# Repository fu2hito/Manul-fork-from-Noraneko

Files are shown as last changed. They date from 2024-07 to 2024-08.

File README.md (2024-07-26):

# Manul(Low profile GRIN layout keyboard based on Noraneko42GR)

## 概要

Manul（Noraneko42GR choc v2）は、[@darakuneko](https://github.com/darakuneko)さんの[Noranekoキーボード](https://github.com/darakuneko/Noraneko)の[Noraneko42gr v1.2](noraneko42gr/v1.2)を元にスイッチをChoc v2(Lofree Ghost switch)に変更したものです。

Manulは[Coffee License](LICENCE_JA.original)にしたがって作成しています。

このREADMEはNoraneko42GRとManul v1.0, 2.0で書きました。

## バージョン

### v1.0

<blockquote class="twitter-tweet"><p lang="ja" dir="ltr">Keyboard: Noraneko42GR / choc v2 mod<br>Switch: いろいろ / Lofree Ghost<br>Keycap: OSA Profile Black Transparent PC Keycap / Maya Imprint nSA<a href="https://twitter.com/hashtag/KEEB_PD?src=hash&amp;ref_src=twsrc%5Etfw">#KEEB_PD</a> <a href="https://twitter.com/hashtag/KEEB_PD_R200?src=hash&amp;ref_src=twsrc%5Etfw">#KEEB_PD_R200</a> <a href="https://t.co/kMvqZM04f1">pic.twitter.com/kMvqZM04f1</a></p>&mdash; fujihito (@fu2hito) <a href="https://twitter.com/fu2hito/status/1797206774899945583?ref_src=twsrc%5Etfw">June 2, 2024</a></blockquote> 

* PCB, Firmwareの動作確認済み
* PCBに設計ミスがあり、空中配線が必要
  * GP13(row0)が配線されていない
  * ソケットの干渉を避ける目的でパッドを削除する必要があり、キーマトリクスの変更とFirmwareの書き換えを含めた修正が必要
* Plateはネジ穴が不足、過度の切り抜きで剛性が不足

### v2.0

<blockquote class="twitter-tweet"><p lang="ja" dir="ltr">Keyboard: Manul(based on Noraneko42GR)<br>Switch: Haute42 Crystal<br>Keycap: Milky White Mist XSA Height<a href="https://twitter.com/hashtag/KEEB_PD?src=hash&amp;ref_src=twsrc%5Etfw">#KEEB_PD</a> <a href="https://twitter.com/hashtag/KEEB_PD_R207?src=hash&amp;ref_src=twsrc%5Etfw">#KEEB_PD_R207</a><br><br>基板、プレート修正して一応の完成です。名前は平べったい猫でマヌルに <a href="https://t.co/Jkr2DkHb3N">pic.twitter.com/Jkr2DkHb3N</a></p>&mdash; fujihito (@fu2hito) <a href="https://twitter.com/fu2hito/status/1814964786993754403?ref_src=twsrc%5Etfw">July 21, 2024</a></blockquote>

* PCBの設計変更
  * ピンアサインの変更を含めて、空中配線が不要になるように変更
  * キーマトリクスの変更
* Plateの設計変更
  * ネジ穴の追加
  * 切り抜きの変更

## Acknowledgement

Manulは直接的には以下の方々のおかげで作成されました。ありがとうございます。

### Noraneko42GR

Manulは[@darakuneko](https://github.com/darakuneko)さんの[Noraneko42gr v1.2](https://github.com/darakuneko/Noraneko/tree/main/noraneko42gr/v1.2)をベースに作成されました。

Noranekoキーボードシリーズは、[Coffee License](https://github.com/darakuneko/Noraneko/blob/main/LICENSE_JA)です。

KiCADファイルやFirmware、プレートファイルは、Noraneko42GRのものを使用しています。

### Choc v2スイッチのフットプリント

Choc v2スイッチのフットプリントは、[サリチル酸](https://github.com/Salicylic-acid3)さんの[KiCAD_FootPrint](https://github.com/Salicylic-acid3/KiCAD_FootPrint)を[フォークしたもの](https://github.com/fu2hito/KiCAD_FootPrint)を使用しました。1.5u等のフットプリントを追加しています。

KiCAD_FootPrintは、[MIT License](https://github.com/Salicylic-acid3/KiCAD_FootPrint/blob/master/Licence.txt)です。

その他[サリチル酸](https://x.com/Salicylic_acid3)さんにはdiscordや書籍などでお世話になっております。

### GPK FWBuilder

Firmwareのビルドは再び[@darakuneko](https://github.com/darakuneko)さんの[GPK FWBuilder](https://github.com/darakuneko/gpk_fwbuilder)を使用しています。
これなしでは私の自キ活は成り立ちません。

Intel Macだと10.1以降動かなくなっているので、Macの更新に迫られています。

### シリアルLEDについて

[monksoffunkJP](https://x.com/monksoffunkJP)さんの[記事](https://25keys.com/2022/05/28/rp2040_sk6812mini/)の下記引用部分を参考に配線しました。きれいに光っております。アドバイスなどあればIssueにてお願いします。

```
もうひとつ解決法があります。しかも面倒なパーツは一切要らない方法です。
それは、WS2812B V5とSK6812mini(-e)を併用するというものです。WS2812Bは3.3VのDINを受けてもDOUTは5Vレベルですので、先にWS2812Bをアンダーグロウとして使い、そのあとにSK6812mini-eをバックライトとして使えば仕様上は動作すると思います。あるいはWS2812Bをレベル変換のために1個だけ載せるという手もあるかもしれませんね。どちらも試したことはないので動かなかったらごめんなさい。
```

### スイッチ裏のRP2040 Zeroの配置について

スイッチのLEDまどを下向きにしたため、RP2040 Zeroのフットプリントはスイッチに干渉します。そのため、使用しないピンのパッドを削除しました。

この配線しないピンのパッドを削除するアイデアは、参考URLを失念しております。申し訳ございません。
たしかTwitterかdiscordで見たものだったかと思います。ありがとうございます。

## ライセンス

* MIT License
  * [LICENSE](./LICENSE)

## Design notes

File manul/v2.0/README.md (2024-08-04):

# Manul

Manul v2 image

ManulはNoraneko42GRをベースにした42キーのGRINレイアウトキーボードです。Lofree Ghostスイッチの利用を前提としたChoc v2ソケット対応です。

## パーツ

* PCB --- 1枚
* アクリルプレート トップ --- 1枚
  * PCBより上
  * 2 mm
* アクリルプレート ボトム1 --- 2枚
  * PCBより下
  * 2 mm
* アクリルプレート ボトム2 --- 1枚
  * PCBより下
  * 2 mm
* M2スペーサー 3mmまたは3.5mm --- 7個
* M2ネジ 3mm --- 14個
* RP2040-Zero --- 1個
* コンスルー --- 18ピン（MAC8 XB-3 高さ3mm以上）
  * ピンヘッダ
  * 干渉を避けるためカットします
* 1N4148W --- 42個
* WS2812B --- 6個
* SK6812MINI-E --- 42個
* Choc V2スイッチ --- 42個
  * アクリルプレート ボトム1が干渉するため、一部のピンの多いChoc V2スイッチは利用できません
* MXキーキャップ（ロープロファイルがおすすめ） --- 42個
* ゴム足 --- 任意の数

## ファームウェア

手順はNoraneko42GRと[同様](./README.original.md)です。Manulには抵抗はありません。

* [ファームウェア](./firmware/manul/)
  * WIP: ビルド済みファイルはアップロードしていません。
* [Vialサポート](https://get.vial.today/)

## はんだ付け

はんだ付けはNoraneko42GRと[同様](./README.original.md)です。Manulには抵抗がありません。

RP2040-Zero、ダイオード、LED、ソケットをはんだ付けします。
いずれもはんだ付けの向きに注意してください。

## 組み立て

1. アクリルプレート トップと一緒にスイッチをPCBに取り付けます。
2. M2スペーサーを取り付けます。まずトップ側にネジ止めします。
3. アクリルプレート ボトム1を取り付けます。ボトム1は2枚使用します。
4. アクリルプレート ボトム2を取り付けます。
5. ネジを取り付けます。
6. アクリルプレート ボトム2にゴム足を取り付けます。

## PCB、アクリルプレートの発注について

PCBは[JLCPCB](https://jlcpcb.com/jp)、アクリルプレートは[Elecrow](https://www.elecrow.com/)で製造したもので動作確認しました。

[PCB](./pcb/)の発注方法は[JLCPCBのFAQ](https://jlcpcb.com/help/article/how-to-generate-gerber-and-drill-files-in-kicad-7)を参考にしてください。

アクリルプレートは[plate](./plate/)のpdfとsvgをzipファイルにしてElecrowにアップロードして発注できます。

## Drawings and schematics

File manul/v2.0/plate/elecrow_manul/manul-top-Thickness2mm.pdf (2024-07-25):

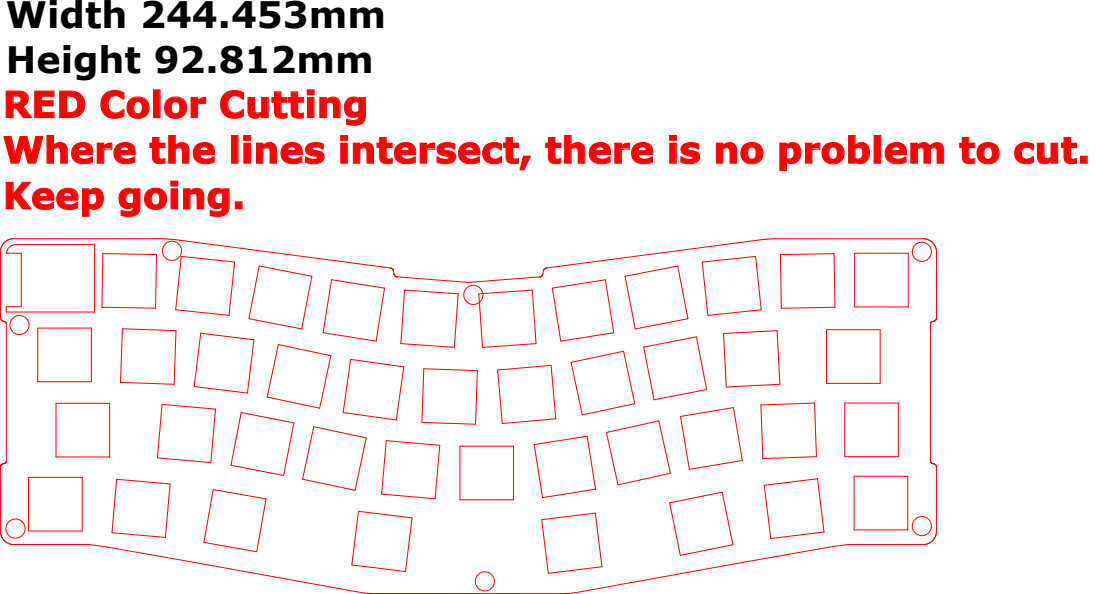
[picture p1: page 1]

Width 244.453mm
Height 92.812mm
RED Color Cutting
Where the lines intersect, there is no problem to cut.
Keep going.

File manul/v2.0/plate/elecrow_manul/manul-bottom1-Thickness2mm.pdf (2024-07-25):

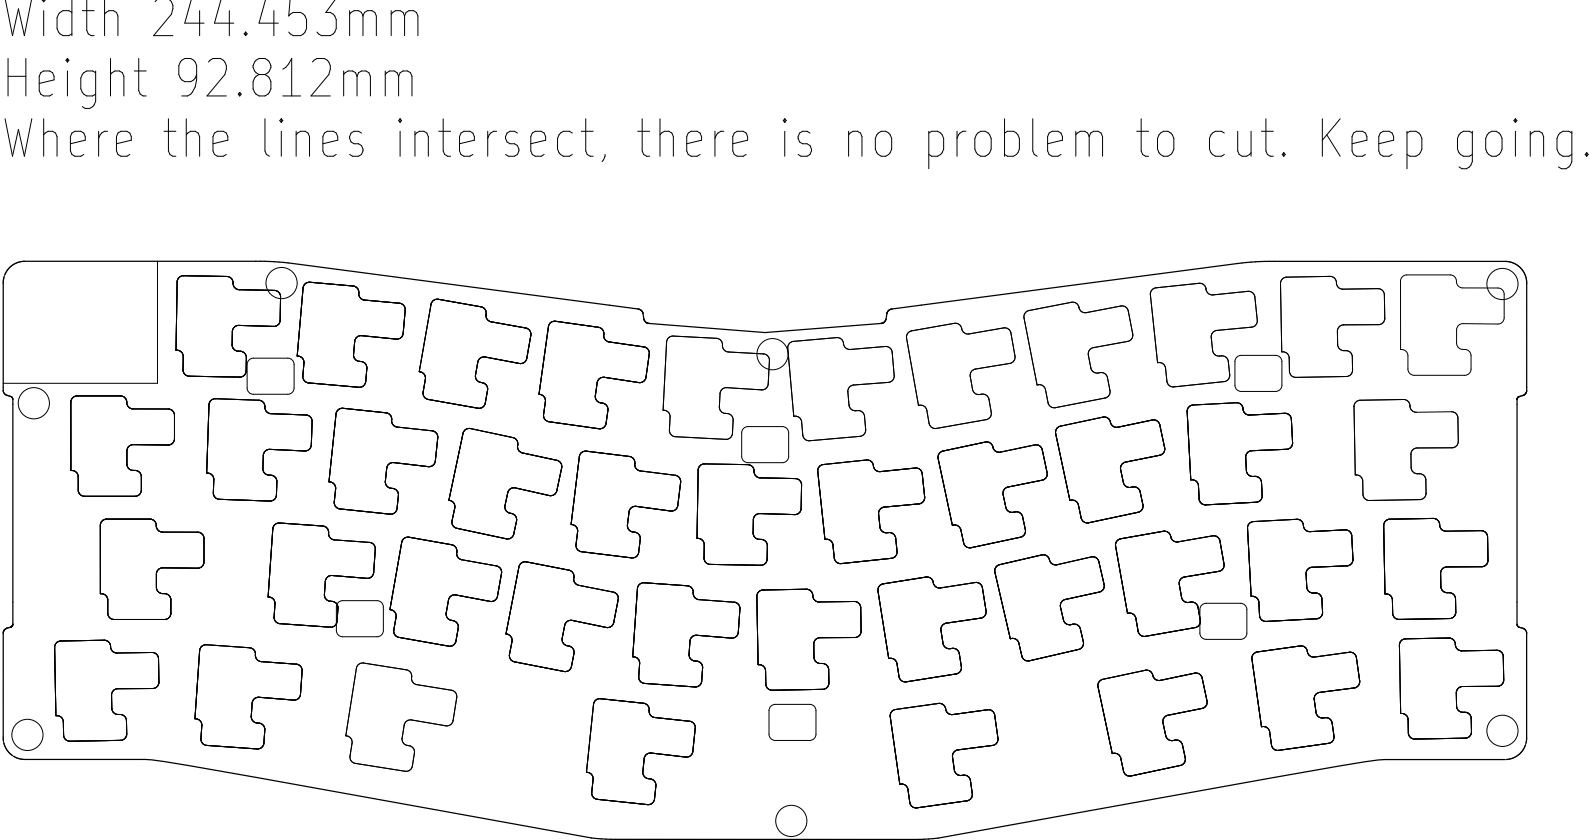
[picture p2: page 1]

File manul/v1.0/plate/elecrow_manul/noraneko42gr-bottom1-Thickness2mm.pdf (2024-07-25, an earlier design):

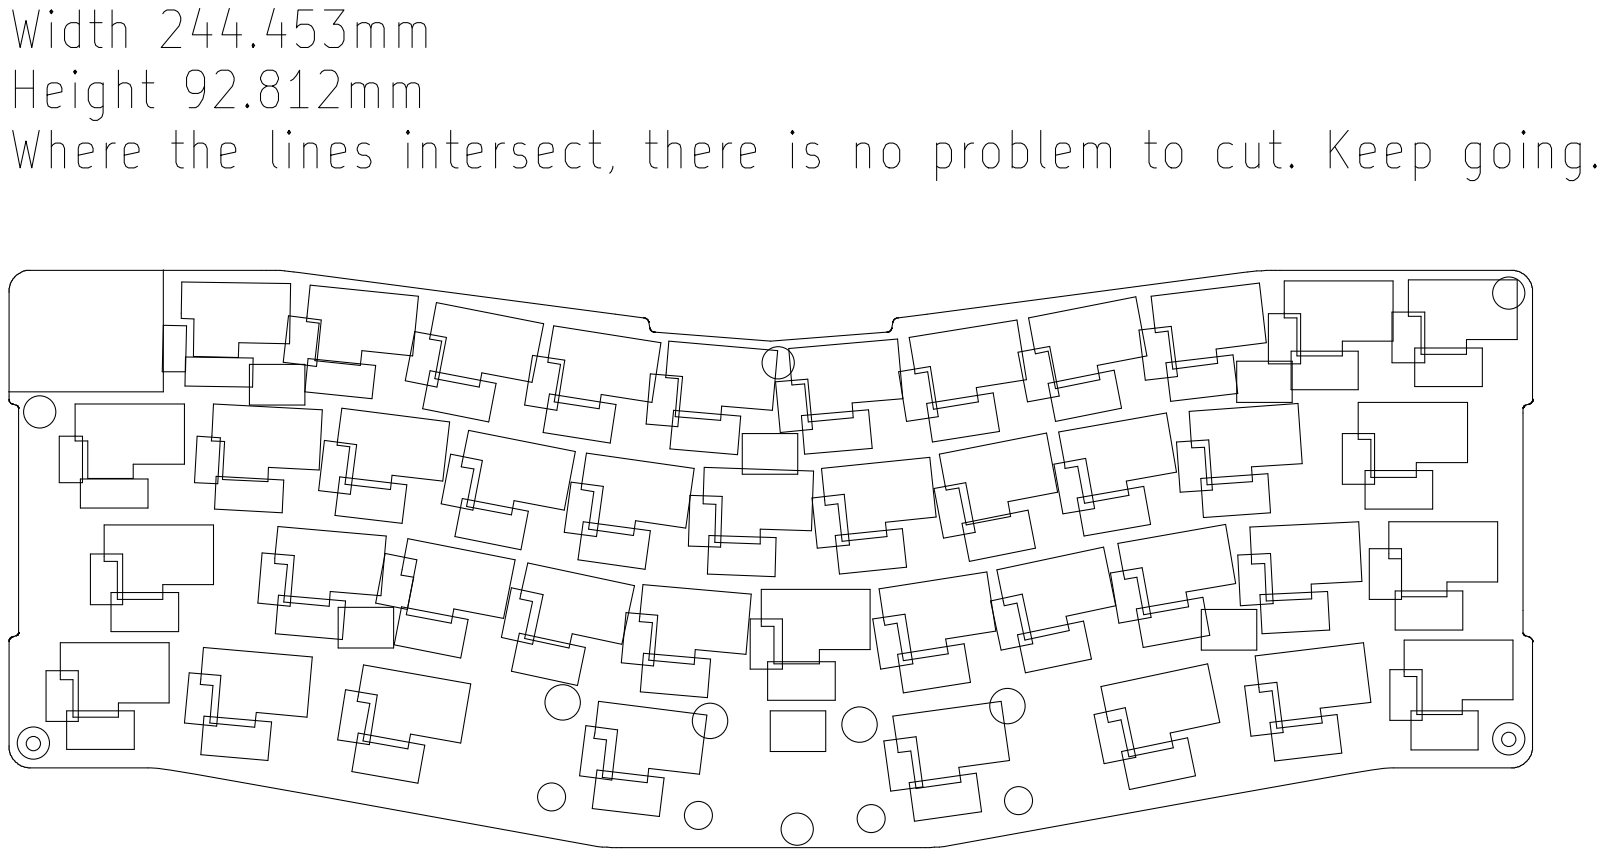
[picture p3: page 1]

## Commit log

2024-07-25 フォーク元のファイルの名前変更
2024-07-25 Noranekoキーボードシリーズの削除
    [noraneko42a.kicad_sch, noraneko42c.kicad_pcb, noraneko42c.kicad_sch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]
2024-07-25 README再追加
2024-07-25 README更新
2024-07-25 submodule追加
2024-07-25 Manulのデータ追加
    [noraneko42gr-B_Mask.gbs, noraneko42gr-B_Paste.gbp, noraneko42gr-B_Silkscreen.gbo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]
2024-07-25 ライセンスファイル追加
2024-07-25 README更新
    キーボードの写真追加
2024-07-25 README更新
    改行追加
2024-07-25 README再更新
    Tweetの埋め込みがうまく行かなかった
2024-07-26 README更新 #2
    Acknowledgementの記載
2024-08-04 アクリルプレートの元ファイルを削除
2024-08-04 README.mdの追加 #3
    ビルドガイド
2024-08-04 ManulのREADME.md更新
    写真追加
